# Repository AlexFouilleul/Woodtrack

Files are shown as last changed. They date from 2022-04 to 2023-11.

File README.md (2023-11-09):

# Bienvenue sur Woodtrack - Une solution pour prévenir du vol de bois 🌳

<p align="center">
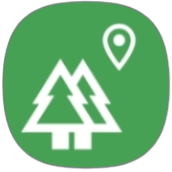
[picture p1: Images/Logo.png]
  
</p>

## 💡 Introduction

Woodtrack est un projet de 2ème année d'école d'ingénieur en filière IESE à Polytech Grenoble. Ce projet vise à proposer une solution destinée à la scierie [Bois Du Dauphinée (BDD)](https://www.scierie-bdd.com/) afin de contrer le problème de vol de bois lors de la livraison de celui-ci.

https://user-images.githubusercontent.com/72225568/165983296-698be7fe-2862-4f15-b2b9-5189bf0c77c5.mp4

## ⚙️ Fonctionnalités

### Le système
- Simple d'implémentation
- Traquer plusieurs positions GPS
- Communication Bluetooth Low Energy (BLE)
- Grande autonomie
- Peu couteux
- Robuste et fiable

### L'application Android
- Simple d'utilisation
- Affichage des positions sur la carte avec des marqueurs
- Les marqueurs peuvent donner l'heure, la latitude et la longitude
- Ouverture de la localisation sélectionnée dans une application tierce (Google Maps)
- Afficher l'historique des positions
- Stockage en mémoire des positions
- Très compacte avec une faible quantité de mémoire utilisée
- Compatible à partir d'Android 2.3 (Gingerbread) 

## 🖼️ Démonstration

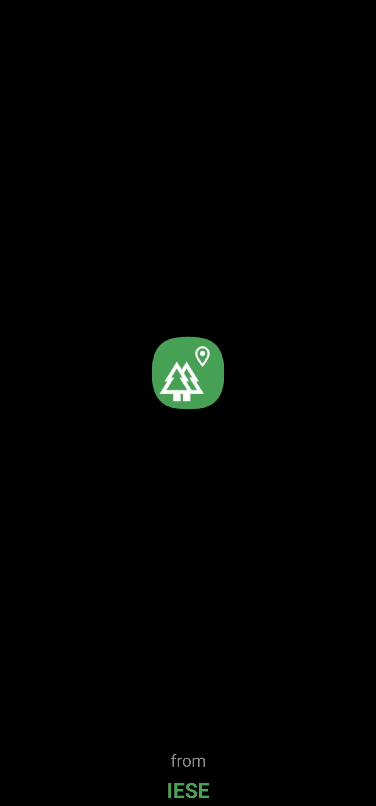
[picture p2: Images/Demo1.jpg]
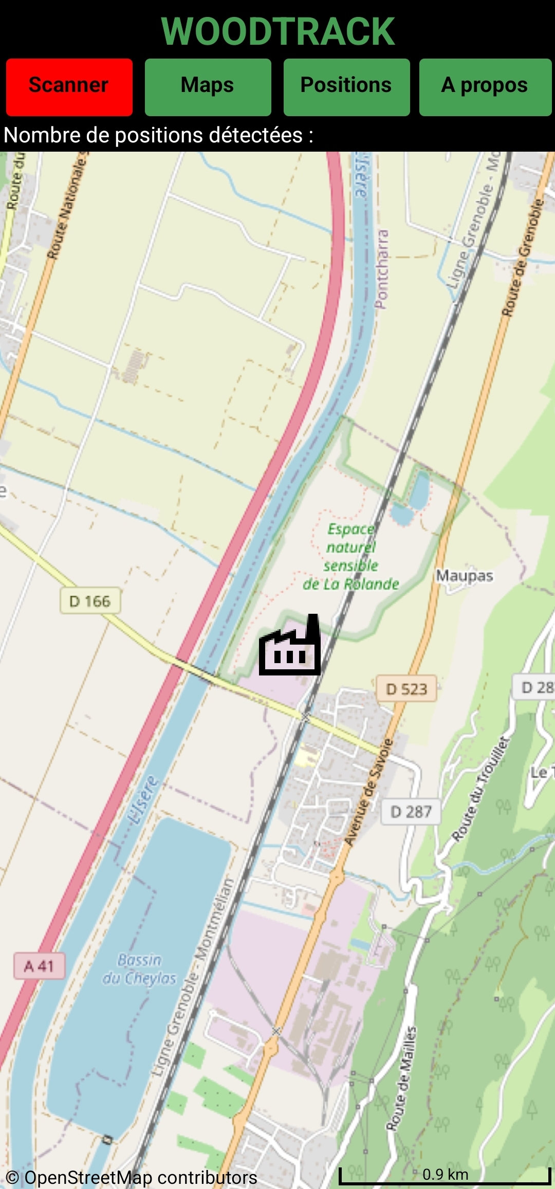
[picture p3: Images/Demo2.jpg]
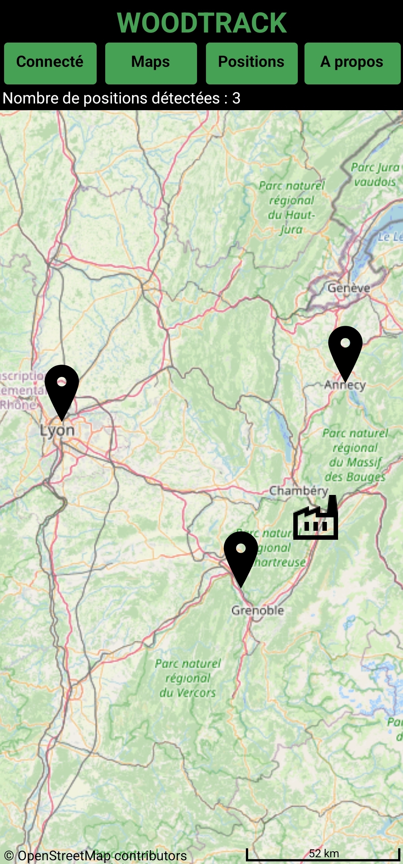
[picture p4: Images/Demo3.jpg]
   

https://user-images.githubusercontent.com/72225568/162793481-6fc9f6b5-7332-4f23-95e1-6f130a6b8214.mp4

## 📂 Guide de démarrage et d'utilisation

### Mise en place du système

1. Connectez l'Arduino au PC et téléversez le programme.
2. Soudez les composants sur le PCB en faisant attention au sens de branchement du connecteur de pile.
3. Connectez la pile et démarrez le système en utilisant l'interrupteur situé sous le module GPS.
4. Installez le boitier sur la sangle.
5. Insérez le système à l'intérieur de la boite et refermez la à l'aide du couvercle.
6. Téléchargez le fichier .apk sur votre smartphone et installez-le.

### Utilisation du système

1. Amusez-vous à fermer et ouvrir la sangle à différents endroits.
2. Ouvrez la sangle, lancez l'application puis cliquez sur le bouton **Scanner**.
3. Sélectionner le traqueur Woodtrack.
4. Patientez quelques secondes pour ensuite apercevoir les différentes positions GPS sur l'application.
5. Vous pouvez cliquer sur les marqueurs et zommer/dézommer pour avoir plus d'informations sur les positions.
6. Une fois la session terminée pensez à vous déconnecter en utilisant le bouton **Déconnexion**.

## 💻 Matériel

- Arduino Nano 33 Ble
- Adafruit Ultimate GPS
- Interrupteur à lame souple (ILS) + Aimants
- Résistance (de 1kΩ)
- Interrupteur 
- Pile 9V + Connecteur pile
- Une sangle à cliquet
- PCB (fichiers fournis)
- Boitier (fichiers fournis)
- Un smartphone Android

## 🧑‍💻 Contributeurs

Anas Bachri (développeur) - [anas.bachri@etu.univ-grenoble-alpes.fr](mailto:anas.Bachri@etu.univ-grenoble-alpes.fr)<br>
Alex Fouilleul (développeur) - [alex.fouilleul@etu.univ-grenoble-alpes.fr](mailto:alex.fouilleul@etu.univ-grenoble-alpes.fr)<br>
Sarah Pallaro (cheffe de projet) - [sarah.pallaro@etu.univ-grenoble-alpes.fr](mailto:sarah.pallaro@etu.univ-grenoble-alpes.fr)<br>

Projets IESE4 - 2022

Par : Polytech Grenoble<br>
De : Université Grenoble Alpes<br>
Pour : Scierie Bois Du Dauphiné

## 📝 Licence

Shield: [][cc-by-nc-sa]

This work is licensed under a
[Creative Commons Attribution-NonCommercial-ShareAlike 4.0 International License][cc-by-nc-sa].

[][cc-by-nc-sa]

[cc-by-nc-sa]: http://creativecommons.org/licenses/by-nc-sa/4.0/
[cc-by-nc-sa-image]: https://licensebuttons.net/l/by-nc-sa/4.0/88x31.png
[cc-by-nc-sa-shield]: https://img.shields.io/badge/License-CC%20BY--NC--SA%204.0-lightgrey.svg

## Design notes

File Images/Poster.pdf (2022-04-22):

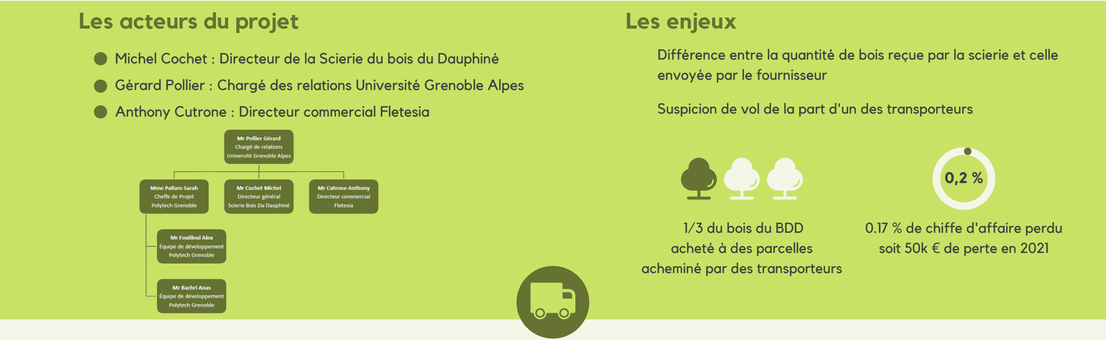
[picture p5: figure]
0.17 % de chiffe d'affaire perdu soit 50k € de perte en 2021; envoyée par le fournisseur; Les acteurs du projet; Les enjeux; 1/3 du bois du BDD acheté à des parcelles acheminé par des transporteurs
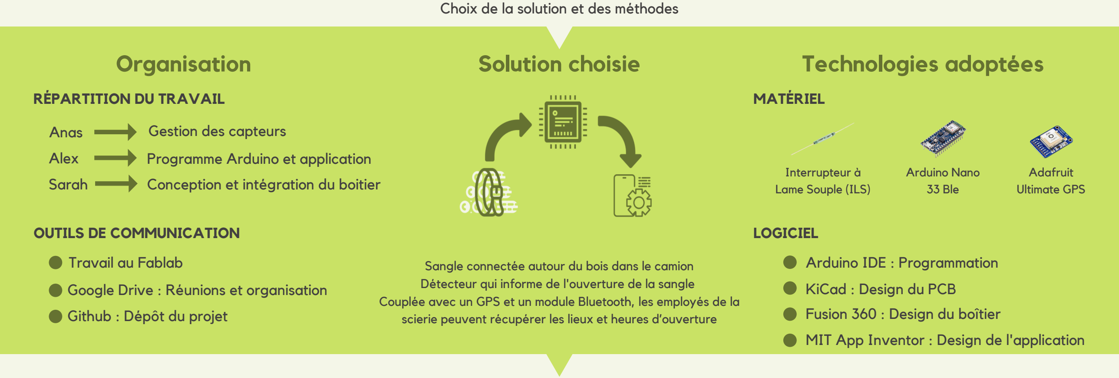
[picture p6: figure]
Anas; Alex; Sarah; Gestion des capteurs; Programme Arduino et application; Conception et intégration du boitier; Travail au Fablab; Google Drive : Réunions et organisation; Github : Dépôt du projet; KiCad : Design du PCB; Fusion 360 : Design du boîtier; Arduino IDE : Programmation; Choix de la solution et des méthodes; Organisation; Solution choisie; Technologies adoptées; LOGICIEL; RÉPARTITION DU TRAVAIL; MATÉRIEL; OUTILS DE COMMUNICATION; Interrupteur à Lame Souple (ILS); Arduino Nano 33 Ble; Adafruit Ultimate GPS

Sangle connectée autour du bois dans le camion Détecteur qui informe de l'ouverture de la sangle Couplée avec un GPS et un module Bluetooth, les employés de la scierie peuvent récupérer les lieux et heures d’ouverture

Michel Cochet : Directeur de la Scierie du bois du Dauphiné

Gérard Pollier : Chargé des relations Université Grenoble Alpes

Anthony Cutrone : Directeur commercial Fletesia

MIT App Inventor : Design de l'application

Prévenir et empêcher le vol de bois Avoir une solution simple d'utilisation, peu couteuse et légale Solution résistante aux chocs et intempéries

# Projet

# Woodtrack

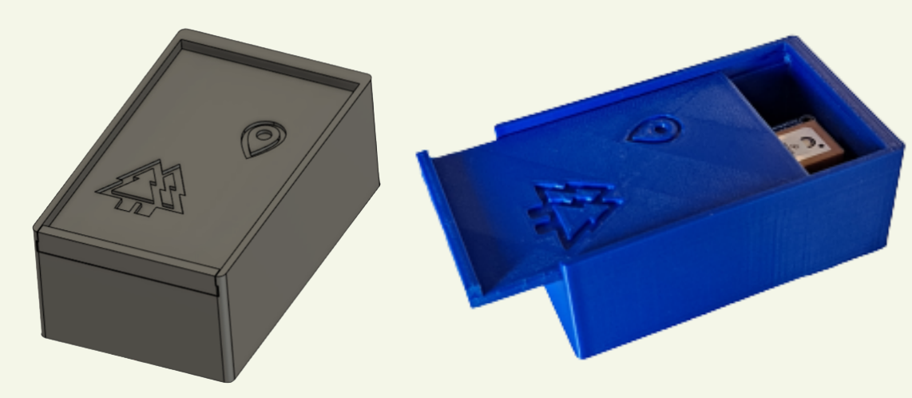
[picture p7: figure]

Anas Bachri
Alex Fouilleul
Sarah Pallaro

Différence entre la quantité de bois reçue par la scierie et celle

LE SYSTÈME ÉLECTRONIQUE

## Les objectifs

## Produit Final

L'ASSEMBLAGE BOITIER-SANGLE | L'APPLICATION ANDROID

Suspicion de vol de la part d'un des transporteurs

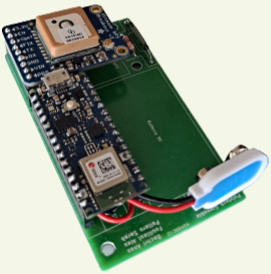
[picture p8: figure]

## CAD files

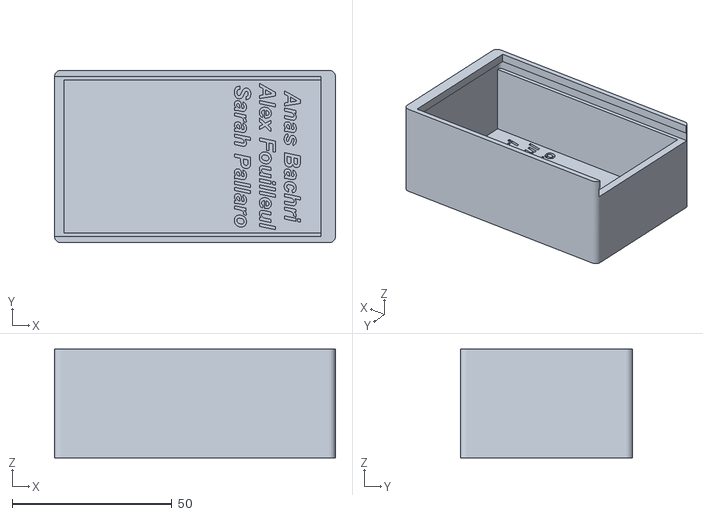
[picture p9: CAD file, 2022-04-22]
Boitier 3D/Boite.stl
88.0 x 54.0 x 34.0

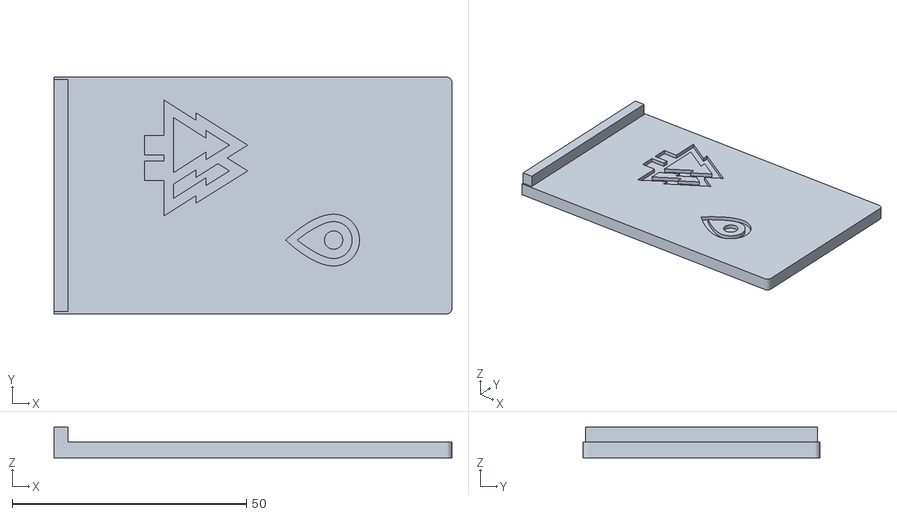
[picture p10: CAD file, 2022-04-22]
Boitier 3D/Couvercle.stl
85.0 x 50.6 x 6.60

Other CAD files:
Boitier 3D/Boite Essai 1 v18.f3d

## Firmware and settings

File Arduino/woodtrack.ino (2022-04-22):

#include <ArduinoBLE.h>
#include <Adafruit_GPS.h>

#define GPSSerial Serial1
#define GPSECHO false

// GPIO
const int ILS = 4;                                                              // ILS
const int GPSEN = 2;                                                            // GPS Enable

// Variables globales
int flag = 0;                                                                   // Flag de présence de données à envoyer
int warning = 0;                                                                // Flag de detection d'ouverture
int envoie = 0;                                                                 // Pointeur du tableau de données
uint32_t timetime = 0;                                                          // Variable contenant le temps en secondes
uint32_t data[9];                                                               // Tableau de données à envoyer [temps1, latitude1, longitude1, temps2, latitude2, ...]

// Objets
Adafruit_GPS GPS(&GPSSerial);                                                   // GPS
BLEService customSensingService("0000180a-0000-1000-8000-00805f9b34fb");        // BLE

// Charatéristiques associés au service
BLEUnsignedIntCharacteristic temps1Characteristic("0000180a-0001-1000-8000-00805f9b34fb", BLERead | BLENotify);
BLEUnsignedIntCharacteristic latitude1Characteristic("0000180a-0002-1000-8000-00805f9b34fb", BLERead | BLENotify);
BLEUnsignedIntCharacteristic longitude1Characteristic("0000180a-0003-1000-8000-00805f9b34fb", BLERead | BLENotify);
BLEUnsignedIntCharacteristic temps2Characteristic("0000180a-0004-1000-8000-00805f9b34fb", BLERead | BLENotify);
BLEUnsignedIntCharacteristic latitude2Characteristic("0000180a-0005-1000-8000-00805f9b34fb", BLERead | BLENotify);
BLEUnsignedIntCharacteristic longitude2Characteristic("0000180a-0006-1000-8000-00805f9b34fb", BLERead | BLENotify);
BLEUnsignedIntCharacteristic temps3Characteristic("0000180a-0007-1000-8000-00805f9b34fb", BLERead | BLENotify);
BLEUnsignedIntCharacteristic latitude3Characteristic("0000180a-0008-1000-8000-00805f9b34fb", BLERead | BLENotify);
BLEUnsignedIntCharacteristic longitude3Characteristic("0000180a-0009-1000-8000-00805f9b34fb", BLERead | BLENotify);

void setup() 
{
  // Economie d'energie
  digitalWrite(PIN_ENABLE_SENSORS_3V3, LOW);        // Eteint les capteurs
  digitalWrite(PIN_ENABLE_I2C_PULLUP, LOW);         // Desactive résistances de tirages I2C
  //digitalWrite(LED_PWR, LOW);
  
  // LED - intégré à la carte, en sortie et éteinte
  pinMode(LED_BUILTIN, OUTPUT);
  digitalWrite(LED_BUILTIN, LOW);

  // ILS - en entrée sur le GPIO 4
  pinMode(ILS, INPUT);

  // UART - communication entre PC/Arduino et Arduino/GPS
  //Serial.begin(9600);
  GPS.begin(9600);

  // Bluetooth
  if (!BLE.begin())
  {
    Serial.println("Erreur initialisation Bluetooth");
    while(1);
  }

  // Paramètrage GPS - se référer à la doc
  GPS.sendCommand(PMTK_SET_NMEA_OUTPUT_RMCGGA);
  GPS.sendCommand(PMTK_SET_NMEA_OUTPUT_RMCONLY);
  GPS.sendCommand(PGCMD_ANTENNA);
  digitalWrite(GPSEN, HIGH);

  // Paramètrage Bluetooth
  BLE.setLocalName("Woodtrack 1 - Beta");
  BLE.setAdvertisedService(customSensingService);
  customSensingService.addCharacteristic(temps1Characteristic);
  customSensingService.addCharacteristic(latitude1Characteristic);
  customSensingService.addCharacteristic(longitude1Characteristic);
  customSensingService.addCharacteristic(temps2Characteristic);
  customSensingService.addCharacteristic(latitude2Characteristic);
  customSensingService.addCharacteristic(longitude2Characteristic);
  customSensingService.addCharacteristic(temps3Characteristic);
  customSensingService.addCharacteristic(latitude3Characteristic);
  customSensingService.addCharacteristic(longitude3Characteristic);
  BLE.addService(customSensingService);
  BLE.setConnectable(true);
  BLE.advertise();
}

void loop()
{
  BLEDevice central = BLE.central();

  // Lecture GPS
  GPS.read();                               // Réception des données GPS

  // Si systeme fermée
  if(digitalRead(ILS) == 0)
  {
    // Allume le GPS
    // digitalWrite(GPSEN, HIGH);                       

    if(warning == 1)                        // Fait l'acquisition si une ouverture à été faite sans avoir  récupéré les données
    {
      if(GPS.newNMEAreceived())             // Traitement des données GPS
      {
        if(!GPS.parse(GPS.lastNMEA()))
        {
          return;
        }
      }
      
      if(GPS.fix)                           // Mise à jour
      {
        Serial.print("\nHeure : ");
        if (GPS.hour < 10) { Serial.print('0'); }
        Serial.print(GPS.hour, DEC); Serial.print(':');
        if (GPS.minute < 10) { Serial.print('0'); }
        Serial.print(GPS.minute, DEC); Serial.print(':');
        if (GPS.seconds < 10) { Serial.print('0'); }
        Serial.println(GPS.seconds, DEC);
        Serial.print("Latitude : ");
        Serial.println(GPS.latitudeDegrees, 4);
        Serial.print("Longitude : ");
        Serial.println(GPS.longitudeDegrees, 4);

        // Conversion temps en secondes
        timetime = GPS.hour*3600 + GPS.minute*60 + GPS.seconds;

        // Stockage des données
        data[envoie] = timetime;
        data[envoie+1] = GPS.latitudeDegrees*10000;
        data[envoie+2] = GPS.longitudeDegrees*10000;

        // --- DEMO A COMMENTER ---
          if(envoie == 3)
          {
            data[4] = 458992; 
            data[5] = 61313;
          }
          if(envoie == 6)
          {
            data[7] = 457764; 
            data[8] = 48535;
          }
        // --- FIN DEMO ---
        
        // Mise à jour des flags
        flag = 1;
        warning = 0;
        envoie = envoie + 3;

        // Eteint le GPS
        //digitalWrite(GPSEN, LOW);
      } 
    }
  }
  else    // Si sangle ouverte
  { 
    if((central) && (flag == 1))             // Si a deja recupéré les données et que l'on se connecte au système
    {
      digitalWrite(LED_BUILTIN, HIGH);
      Serial.print("\nConnecté à : ");
      Serial.println(central.address());

      if((central.connected()) && (flag == 1)) 
      {
        temps1Characteristic.writeValue(data[0]);
        latitude1Characteristic.writeValue(data[1]);
        longitude1Characteristic.writeValue(data[2]);
        Serial.print("--> Envoie position 1\n");
 
        if(envoie >= 6)
        {
          delay(1000);
          temps2Characteristic.writeValue(data[3]);
          latitude2Characteristic.writeValue(data[4]);
          longitude2Characteristic.writeValue(data[5]);
          Serial.print("--> Envoie position 2\n");
        }
        if(envoie >= 9)
        {
          delay(1000);
          temps3Characteristic.writeValue(data[6]);
          latitude3Characteristic.writeValue(data[7]);
          longitude3Characteristic.writeValue(data[8]);
          Serial.print("--> Envoie position 3\n");
        }

        //Remise à 0 des flags de detection et avertissement et des data
        flag = 0;
        warning = 0;
        envoie = 3;
        memset(data, 0, sizeof(data)/sizeof(data[0]));
      }
      
      digitalWrite(LED_BUILTIN, LOW);
      Serial.println("Connection terminée");
    }
    else                                // Si on a deja récupéré les données mais pas de connexion au système
    {
      warning = 1;
    }
  }
}

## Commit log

2022-04-08 Add Arduino program
2022-04-08 Boitier Fusion 360
    V18
    [Boite Essai 1 v18.f3d]
2022-04-10 Create KiCad folder
2022-04-10 Gerber files for PCB printing
2022-04-10 KiCad PCB project
2022-04-10 Add Arduino Code
2022-04-22 Optimizations + Power consumption
2022-04-22 Add STL files
    [Boite.stl, Couvercle.stl]
2023-11-09 Update README.md
    Align adresse mail case sensitive
